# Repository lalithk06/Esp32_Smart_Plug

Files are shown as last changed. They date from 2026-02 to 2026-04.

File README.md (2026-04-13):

# ⚡ ESP32 Smart Plug — Hardware Reference Design
*A compact and efficient smart plug built around the ESP32-S3 for intelligent power control, protection, and connectivity.*

This project presents the schematic and PCB design of a smart plug capable of switching AC loads while supporting modern embedded features such as USB connectivity, RTC support, and protection circuitry. Designed to explore real-world embedded hardware development and PCB design practices.

> 📺 This project was developed by following a YouTube playlist by **Ampnics**, with additional learning and implementation.

---

## ⚙ Working Principle

* The system uses an **ESP32-S3 microcontroller** as the core processing unit.
* AC mains input is stepped down and regulated to provide safe DC power for the controller.
* A **relay switching circuit** enables the ESP32 to control connected appliances.
* Protection components safeguard the device against voltage spikes and electrical faults.
* USB connectivity allows programming and debugging.
* RTC support enables future time-based automation features.

---

## 📌 Objective
To design and develop a reliable hardware platform for a smart plug that demonstrates safe mains power handling, embedded control, and scalable architecture for future IoT-based automation.

---

## ⚙ Components Used

| No. | Components | Specifications / Role |
| :---: | :---: | :---: |
| 1. | ESP32-S3 Module | Main microcontroller with Wi-Fi & BLE |
| 2. | Relay | AC load switching |
| 3. | AC-DC Power Module | Converts mains to regulated DC |
| 4. | Voltage Regulators | Stable voltage supply |
| 5. | Protection Circuitry | Fuse, MOV, flyback diode, etc. |
| 6. | USB Interface | Programming & debugging |
| 7. | Capacitors & Resistors | Filtering and biasing |
| 8. | RTC (Optional) | Time-based control support |

---

## 📷 Preview

### 🖼 Schematic Diagram  
<div align="center">
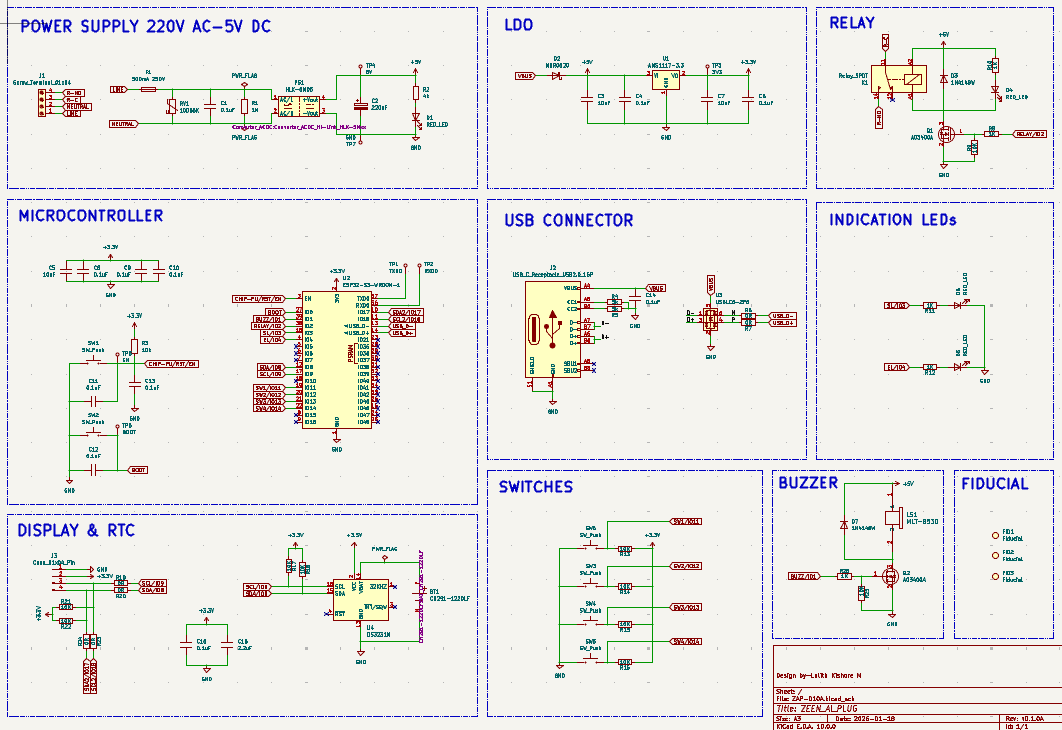
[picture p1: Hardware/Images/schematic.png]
  
</div>

### 📐 PCB Layout  
<div align="center">
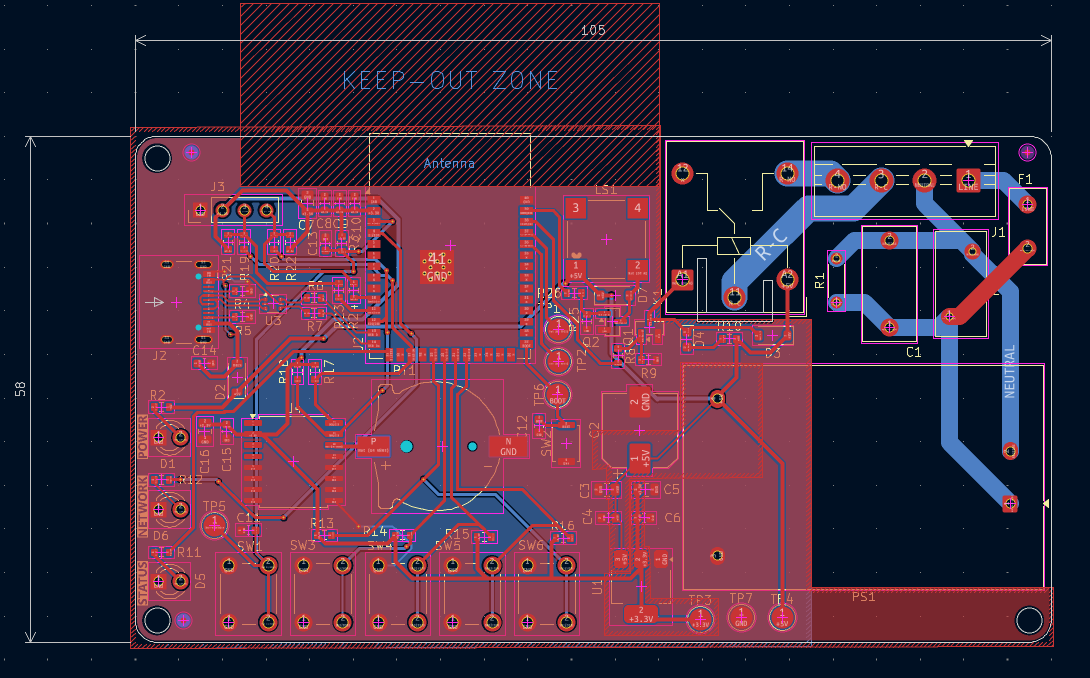
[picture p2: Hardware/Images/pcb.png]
  
</div>

### 🧊 3D View  
<div align="center">
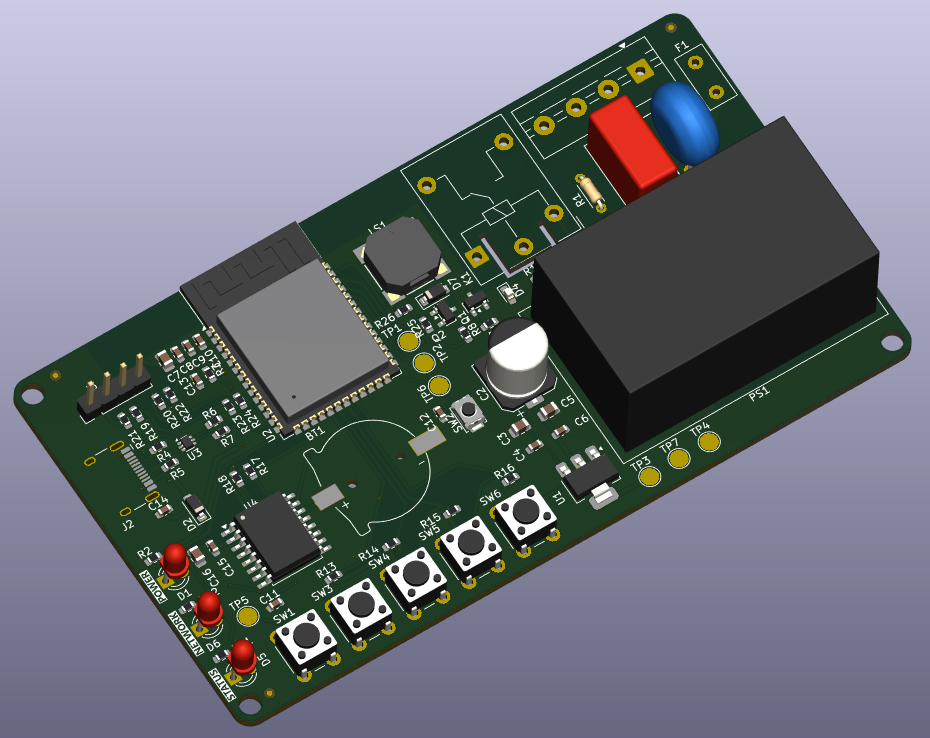
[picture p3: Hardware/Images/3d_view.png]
  
</div>

---

## 🧠 Design Highlights

- Proper isolation between AC mains and low-voltage sections  
- Dedicated power zoning for noise reduction  
- Flyback protection for relay reliability  
- USB interface for easy firmware flashing  

---

## ⚠ Safety Considerations

- Isolation maintained between high-voltage and low-voltage domains  
- Proper creepage and clearance followed  
- Fuse and MOV used for protection  
- Designed for educational and prototyping purposes only  

---

## 📊 Specifications

| Parameter | Value |
|---|---|
| Input Voltage | 230V AC |
| Output Control | Relay-based switching |
| MCU | ESP32-S3 |
| Communication | Wi-Fi, BLE |

---

## 🚀 Key Highlights

✅ Designed with real-world electrical safety considerations  
✅ Suitable for home automation applications  
✅ Expandable for IoT integration  
✅ Compact PCB layout  
✅ Industry-relevant hardware design workflow  

---

## 🔄 Future Improvements

- Energy monitoring (current & voltage sensing)  
- Mobile app / cloud integration  
- Overload and thermal protection  
- Smart scheduling and automation  
- Voice assistant compatibility  
- Custom enclosure design  
- Power consumption optimization  

---

⭐ *This project is part of my learning journey in hardware design and PCB development.*

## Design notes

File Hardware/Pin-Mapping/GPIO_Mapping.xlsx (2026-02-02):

ZEEN-AI-PLUG | GPIO MAPPING
Device | GPIO | PIN | Type | Comment
3.3V |  | 2 | PWR
GND |  | 1 or 40 | PWR
VBUS |  |  | PWR
USB_D+ | IO20 | 14 | PROGRAM/DEBUG
USB_D- | IO19 | 13 | PROGRAM/DEBUG
SW1 | EN | 3 | IN
SW2 | IO0 | 27 | IN
SW3 | IO11 | 19 | IN
SW4 | IO12 | 20 | IN
SW5 | IO13 | 21 | IN
SW6 | IO14 | 22 | IN
RTC_sda | IO8 | 12 | COMM
RTC_scl | IO9 | 17 | COMM
DIS_sda | IO8 | 12 | COMM/OP
DIS_scl | IO9 | 17 | COMM/OP
OPT_dis_sda | IO17 | 10 | COMM/OP
OPT_dis_scl | IO18 | 11 | COMM/OP
Relay | IO2 | 38 | OP
Network-LED | IO4 | 4 | OP
Status-LED | IO3 | 15 | OP
Buzzer | IO1 | 39 | OP

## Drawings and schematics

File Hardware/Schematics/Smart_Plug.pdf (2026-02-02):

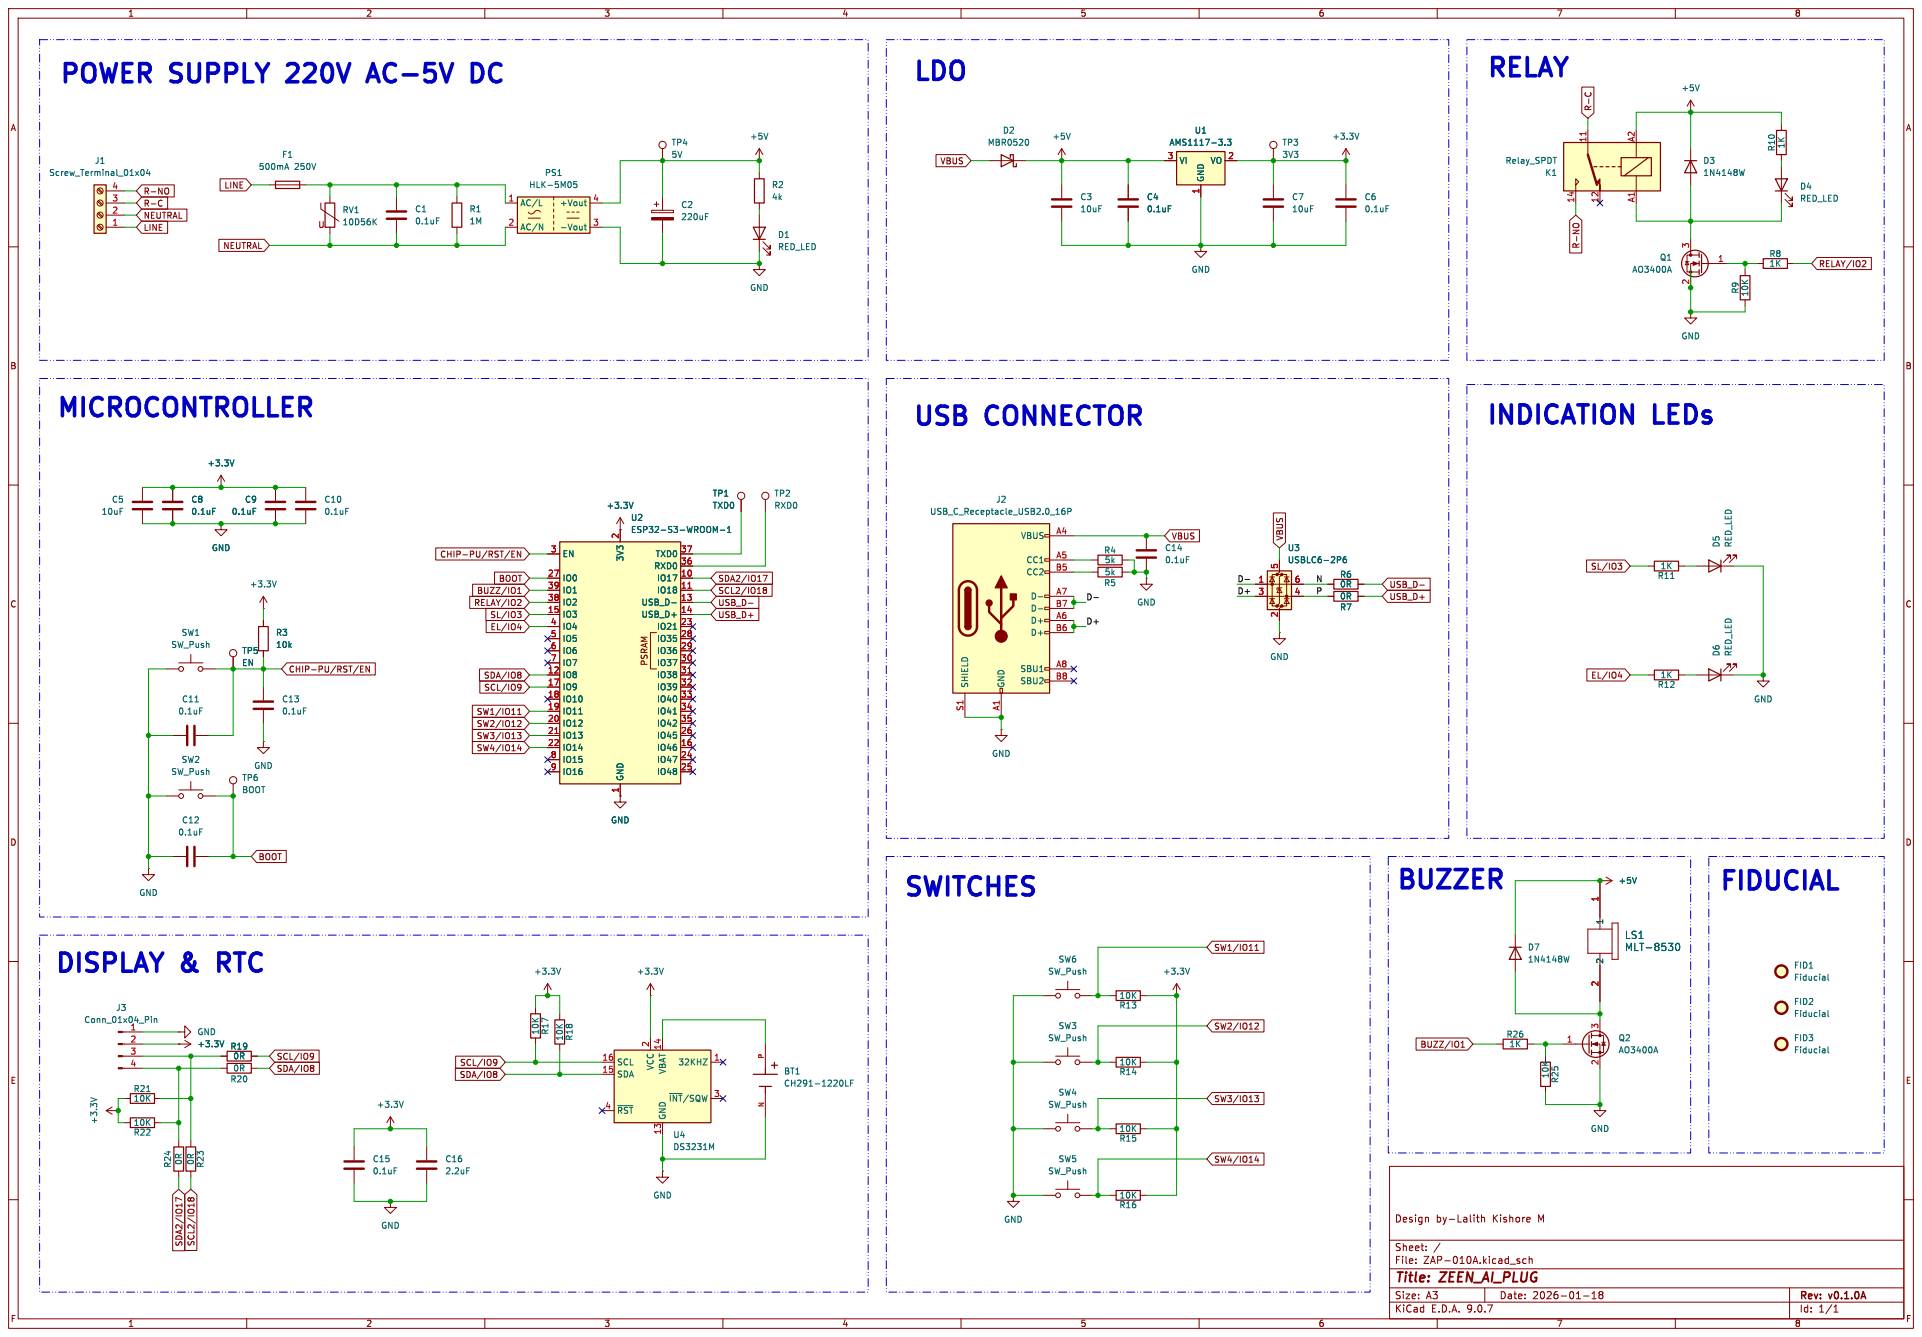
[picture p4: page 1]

POWER SUPPLY 220V AC-5V DC

BOOT CHIP-PU/RST/EN

BUZZ/IO1 RELAY/IO2 EL/IO4 SL/IO3 CHIP-PU/RST/EN

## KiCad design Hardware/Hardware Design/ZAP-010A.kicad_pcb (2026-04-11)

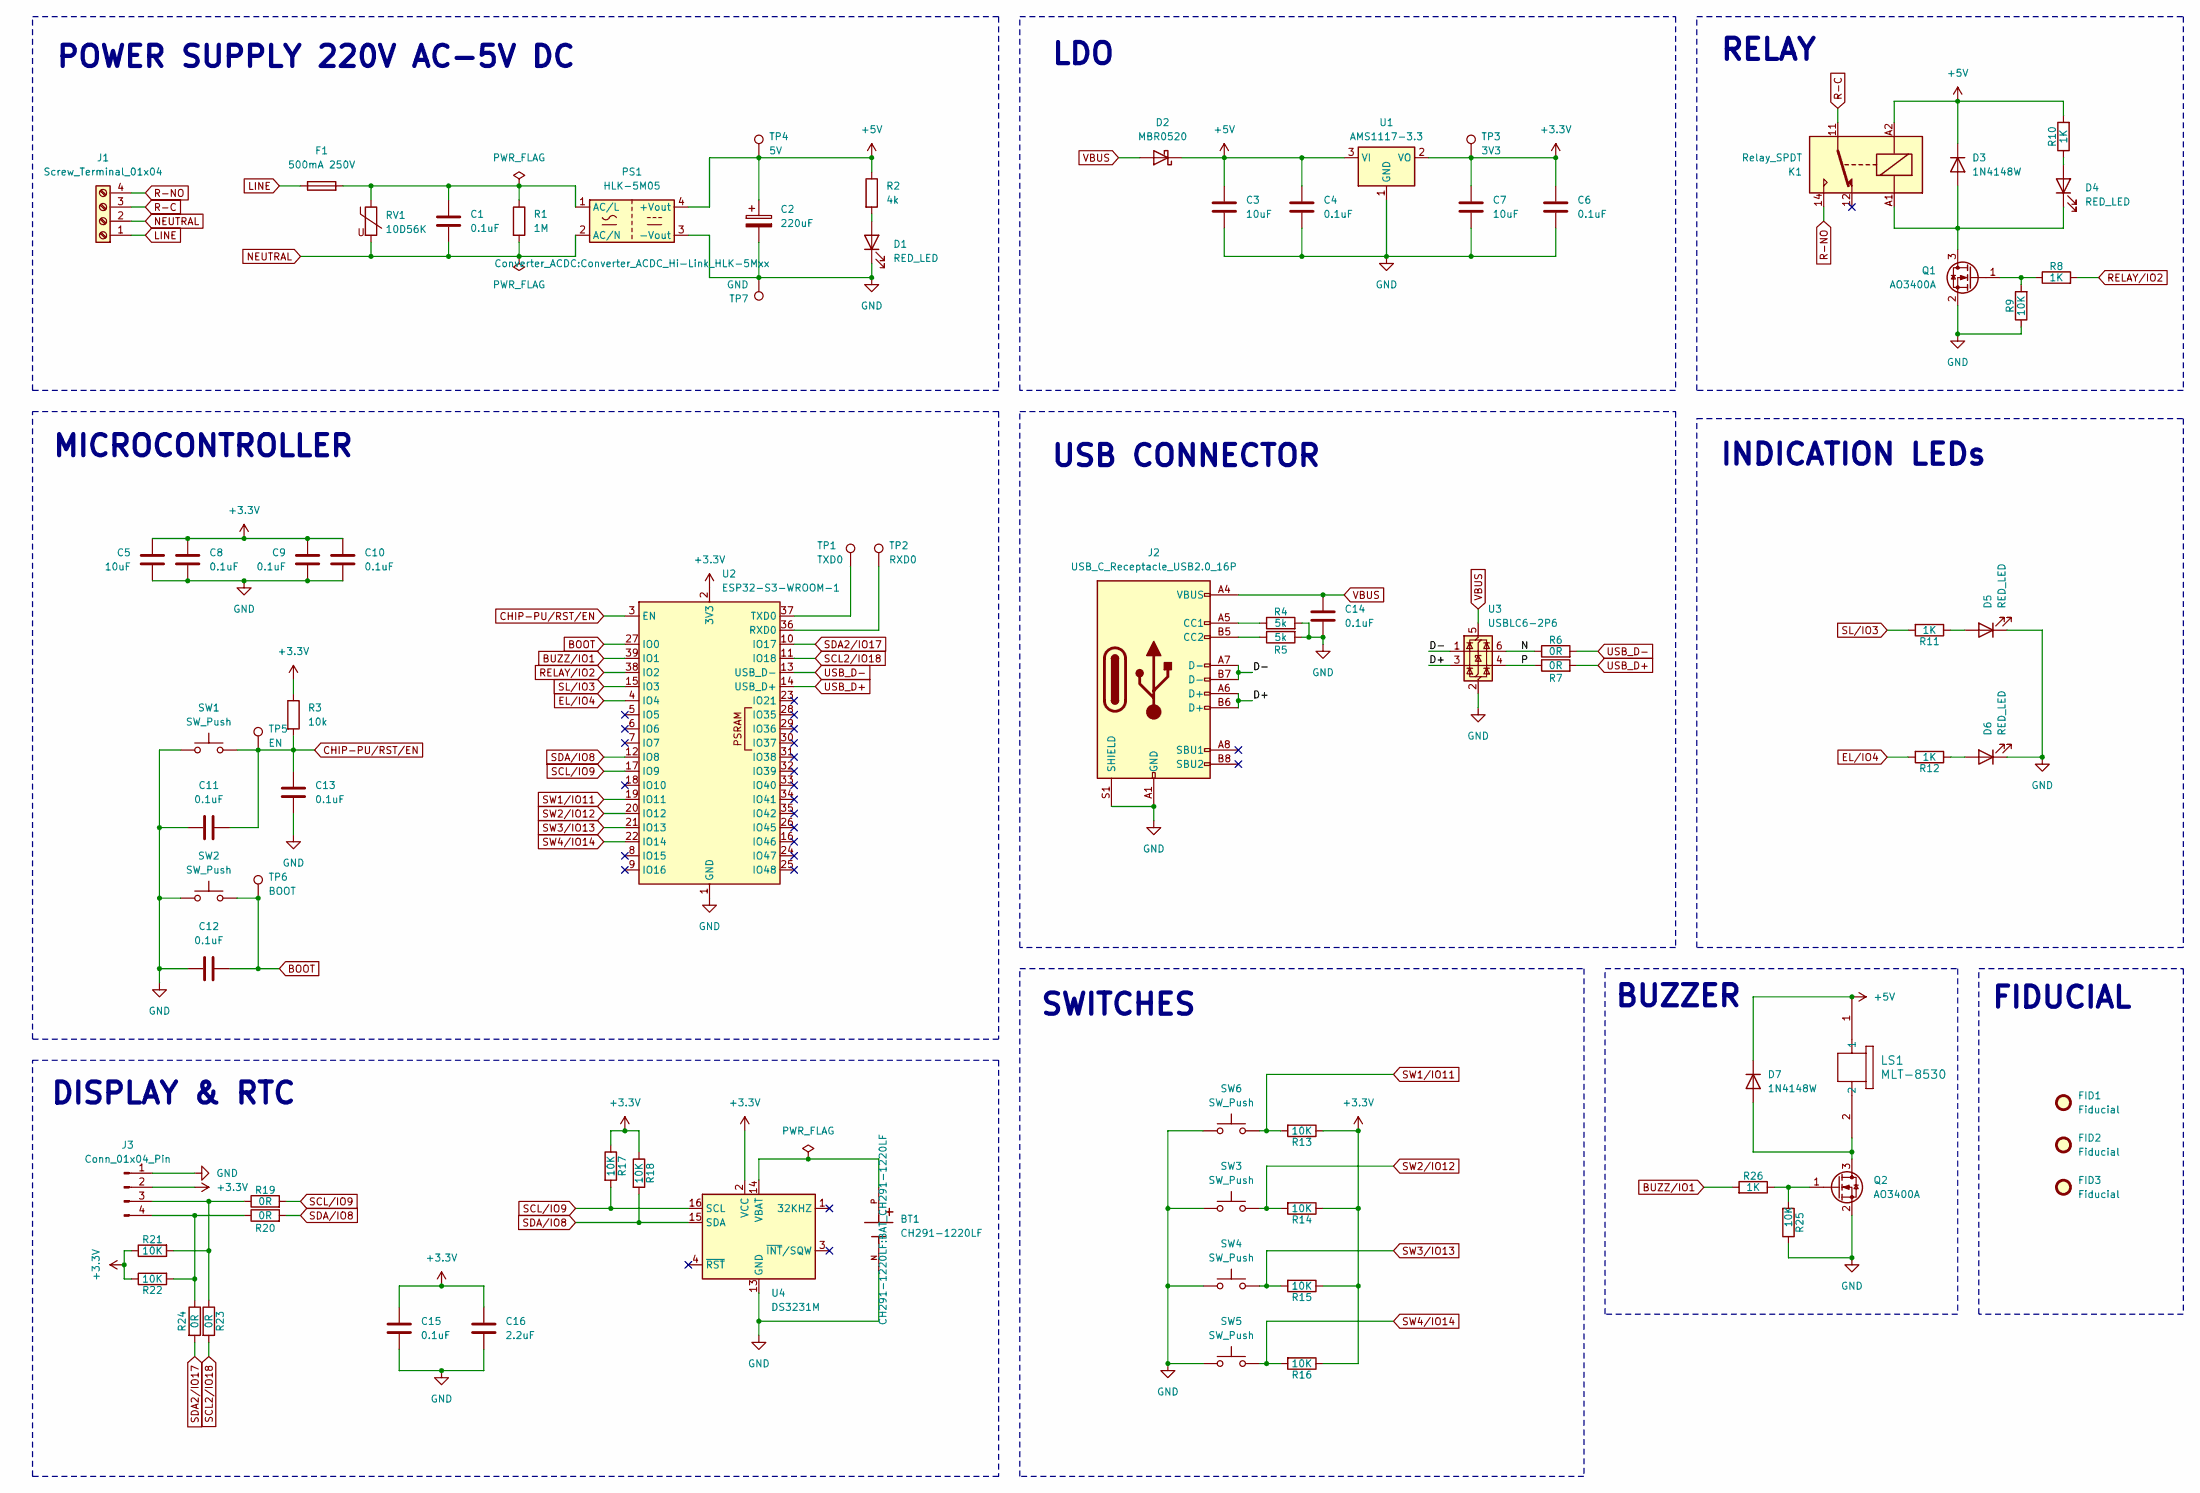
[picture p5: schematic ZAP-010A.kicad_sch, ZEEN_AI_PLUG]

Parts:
BT1: CH291-1220LF; BAT_CH291-1220LF; PARTREV A
C1: 0.1uF; C_Rect_L13.0mm_W6.0mm_P10.00mm_FKS3_FKP3_MKS4
C2: 220uF; CP_Elec_8x10
C3, C5, C7: 10uF; C_0805_2012Metric
C4, C6, C8, C9, C10, C11, C12, C13, C14, C15: 0.1uF; C_0603_1608Metric
C16: 2.2uF; C_0805_2012Metric
D1, D5, D6: RED_LED; LED_D3.0mm
D2: MBR0520; D_SOD-123
D3, D7: 1N4148W; D_SOD-123
D4: RED_LED; LED_0603_1608Metric_Pad1.05x0.95mm_HandSolder
F1: 500mA 250V; Fuse_Littelfuse_395Series
FID1, FID2, FID3: Fiducial; Fiducial_0.75mm_Mask1.5mm
J1: Screw_Terminal_01x04; TerminalBlock_MaiXu_MX126-5.0-04P_1x04_P5.00mm
J2: USB_C_Receptacle_USB2.0_16P; USB_C_Receptacle_HCTL_HC-TYPE-C-16P-01A
J3: Conn_01x04_Pin; PinHeader_1x04_P2.54mm_Vertical
K1: Relay_SPDT; Relay_SPDT_Hongfa_HF3F-L-xx-1ZL1T
LS1: MLT-8530; MLT-8530_JHE
PS1: HLK-5M05; Converter_ACDC_Hi-Link_HLK-5Mxx
Q1, Q2: AO3400A; SOT-23
R1: 1M; R_Axial_DIN0204_L3.6mm_D1.6mm_P5.08mm_Horizontal
R2: 4k; R_0603_1608Metric
R3: 10k; R_0603_1608Metric
R4, R5: 5k; R_0603_1608Metric
R6, R7, R19, R20, R23, R24: 0R; R_0603_1608Metric
R8, R10, R11, R12, R26: 1K; R_0603_1608Metric
R9, R13, R14, R15, R16, R17, R18, R21, R22, R25: 10K; R_0603_1608Metric
RV1: 10D56K; RV_Disc_D12mm_W5.8mm_P7.5mm
SW1, SW3, SW4, SW5, SW6: SW_Push; SW_PUSH_6mm
SW2: SW_Push; SW_Push_SPST_NO_Alps_SKRK
TP1: TXD0; TestPoint_Pad_D2.5mm
TP2: RXD0; TestPoint_Pad_D2.5mm
TP3: 3V3; TestPoint_Pad_D2.5mm
TP4: 5V; TestPoint_Pad_D2.5mm
TP5: EN; TestPoint_Pad_D2.5mm
TP6: BOOT; TestPoint_Pad_D2.5mm
TP7: GND; TestPoint_Pad_D2.5mm
U1: AMS1117-3.3; SOT-223-3_TabPin2
U2: ESP32-S3-WROOM-1
U3: USBLC6-2P6; SOT-666
U4: DS3231M; SOIC-16W_7.5x10.3mm_P1.27mm

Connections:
+3.3V: C5.1, C6.1, C7.1, C8.1, C9.1, C10.1, C15.2, C16.2, J3.2, R3.1, R13.1, R14.1, R15.1, R16.1, R17.1, R18.1, R21.1, R22.1, TP3.1, U1.2 (VO), U2.2 (3V3), U4.2 (VCC)
+5V: C2.1, C3.1, C4.1, D2.1 (K), D3.1 (K), D7.1 (K), K1.A2, LS1.1, PS1.4 (+Vout), R2.1, R10.2, TP4.1, U1.3 (VI)
/D+: J2.A6 (D+), J2.B6 (D+), U3.3 (I/O2)
/D-: J2.A7 (D-), J2.B7 (D-), U3.1 (I/O1)
/N: R6.1, U3.6 (I/O1)
/P: R7.1, U3.4 (I/O2)
BOOT: C12.2, SW2.2, TP6.1, U2.27 (IO0)
BUZZ/IO1: R26.2, U2.39 (IO1)
CHIP-PU/RST/EN: C11.2, C13.1, R3.2, SW1.2, TP5.1, U2.3 (EN)
EL/IO4: R12.2, U2.4 (IO4)
GND: BT1.N, C2.2, C3.2, C4.2, C5.2, C6.2, C7.2, C8.2, C9.2, C10.2, C11.1, C12.1, C13.2, C14.2, C15.1, C16.1, D1.1 (K), D5.1 (K), D6.1 (K), J2.A1 (GND), J2.A12 (GND), J2.B1 (GND), J2.B12 (GND), J2.S1 (SHIELD), J3.1, PS1.3 (-Vout), Q1.2 (S), Q2.2 (S), R4.2, R5.2, R9.1, R25.1, SW1.1, SW2.1, SW3.1, SW4.1, SW5.1, SW6.1, TP7.1, U1.1 (GND), U2.1 (GND), U2.40 (GND), U2.41 (GND), U3.2 (GND), U4.5 (GND), U4.6 (GND), U4.7 (GND), U4.8 (GND), U4.9 (GND), U4.10 (GND), U4.11 (GND), U4.12 (GND), U4.13 (GND)
LINE: F1.1, J1.1
NEUTRAL: C1.2, J1.2, PS1.2 (AC/N), R1.2, RV1.2
unnamed: D1.2 (A), R2.2
unnamed: D3.2 (A), D4.1 (K), K1.A1, Q1.3 (D)
unnamed: D4.2 (A), R10.1
unnamed: D5.2 (A), R11.1
unnamed: D6.2 (A), R12.1
unnamed: D7.2 (A), LS1.2, Q2.3 (D)
unnamed: J2.A5 (CC1), R4.1
unnamed: J2.B5 (CC2), R5.1
unnamed: J3.3, R19.1, R21.2, R23.1
unnamed: J3.4, R20.1, R22.2, R24.1
unnamed: C1.1, F1.2, PS1.1 (AC/L), R1.1, RV1.1
unnamed: Q1.1 (G), R8.1, R9.2
unnamed: Q2.1 (G), R25.2, R26.1
unnamed: TP2.1, U2.36 (RXD0)
unnamed: TP1.1, U2.37 (TXD0)
unnamed: BT1.P, U4.14 (VBAT)
R-C: J1.3, K1.11
R-NO: J1.4, K1.14
RELAY/IO2: R8.2, U2.38 (IO2)
SCL2/IO18: R23.2, U2.11 (IO18)
SCL/IO9: R17.2, R19.2, U2.17 (IO9), U4.16 (SCL)
SDA2/IO17: R24.2, U2.10 (IO17)
SDA/IO8: R18.2, R20.2, U2.12 (IO8), U4.15 (SDA)
SL/IO3: R11.2, U2.15 (IO3)
SW1/IO11: R13.2, SW6.2, U2.19 (IO11)
SW2/IO12: R14.2, SW3.2, U2.20 (IO12)
SW3/IO13: R15.2, SW4.2, U2.21 (IO13)
SW4/IO14: R16.2, SW5.2, U2.22 (IO14)
USB_D+: R7.2, U2.14 (USB_D+)
USB_D-: R6.2, U2.13 (USB_D-)
VBUS: C14.1, D2.2 (A), J2.A4 (VBUS), J2.A9 (VBUS), J2.B4 (VBUS), J2.B9 (VBUS), U3.5 (VBUS)

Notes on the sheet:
DISPLAY & RTC
MICROCONTROLLER
LDO
FIDUCIAL
POWER SUPPLY 220V AC-5V DC
BUZZER
INDICATION LEDs
SWITCHES
USB CONNECTOR
RELAY

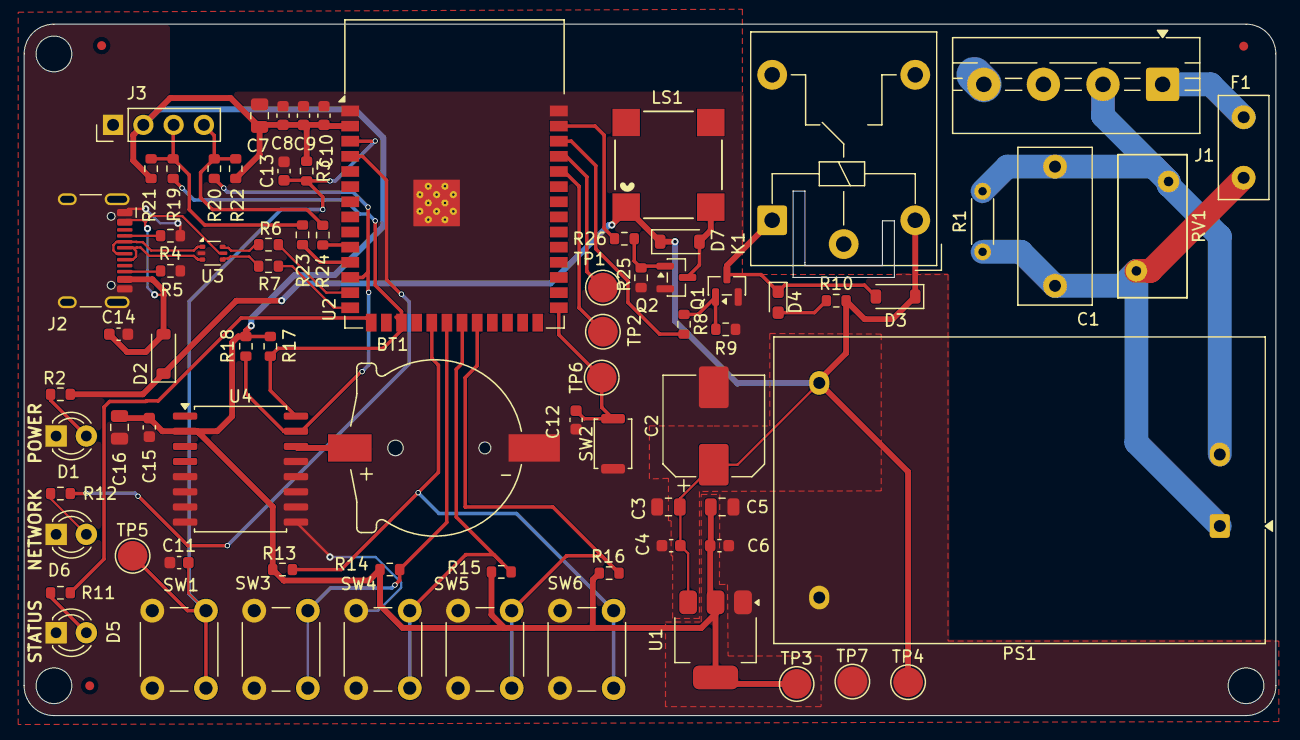
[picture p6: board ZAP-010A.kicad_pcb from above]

Board: 2 copper layers, 105.0 x 58.0 mm, 80 parts (0 on the bottom side), 44 nets.

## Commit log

2026-02-02 Renamed folder
    [ZAP-010A.kicad_pcb, ZAP-010A.kicad_sch]
2026-02-15 PCB edited
    [ZAP-010A.kicad_pcb]
2026-03-13 PCB layout and arrangements are done
    [ZAP-010A.kicad_pcb, ZAP-010A.kicad_sch]
2026-03-13 Routing completed
    [ZAP-010A.kicad_pcb]
2026-03-14 ERC and DRC done
    [ZAP-010A.kicad_pcb, ZAP-010A.kicad_sch]
2026-04-11 DRC errors cleared
    [ZAP-010A.kicad_pcb]
2026-04-11 3D model added
    [ZAP-010A.kicad_pcb]
2026-04-11 Manufacturing Files generated
    [ZAP-010A-B_Cu.gbr, ZAP-010A-B_Mask.gbr, ZAP-010A-B_Paste.gbr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]
2026-04-13 Images added
    [GPIO_Mapping.xlsx]
2026-04-13 Removed ignored folders from tracking
    [CH291-1220LF.step, MLT-8530--3DModel-STEP-269445.STEP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]
2026-04-15 Charging module and buck converetr added
